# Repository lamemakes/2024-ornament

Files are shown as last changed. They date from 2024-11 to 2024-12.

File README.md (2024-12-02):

# ✨ Blinky Tree ✨

**A super simple holiday ornament that whimsically blinks some LEDs**

## How's it work?

This utilizes [charlieplexing](https://en.wikipedia.org/wiki/Charlieplexing) & an ATTiny85 to control 12 LEDs. When it isn't flashing it's LEDs due to a button trigger, the ATTiny is in a state of [deep sleep ](https://onlinedocs.microchip.com/oxy/GUID-317042D4-BCCE-4065-BB05-AC4312DBC2C4-en-US-2/GUID-0EC704BC-648F-4BF6-90AE-0FAF9C596013.html) and thus using very little power, which is why it can be powered with a CR2032.

## Pics

*Schematic*
2024 Tree Ornament Schematic

*PCB*
2024 Tree Ornament PCB

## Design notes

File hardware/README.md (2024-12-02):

# ⚙️ Blinky Tree Hardware

## BOM

| Part No. | Link | Quantity | Notes | 
|---|---|---|---|
| BC-2003-FH-TR | https://www.digikey.com/en/products/detail/mpd-memory-protection-devices/BC-2003-FH-TR/16692312 | 1 | CR2032 Battery Holder |
| 151031VS06000 | https://www.digikey.com/en/products/detail/w%C3%BCrth-elektronik/151031VS06000/4489988 | 6 | Green LED |
| 151031SS06000 | https://www.digikey.com/en/products/detail/w%C3%BCrth-elektronik/151031SS06000/4489982 | 6 | Red LED |
| TL1107BF130WQ | https://www.digikey.com/en/products/detail/e-switch/TL1107BF130WQ/378978 | 1 | Button |
| ATTINY85-20PU-ND | https://www.digikey.com/en/products/detail/microchip-technology/ATTINY85-20PU/735469 | 1 | "Brains" of the operation |
| CF18JT200R | https://www.digikey.com/en/products/detail/stackpole-electronics-inc/CF18JT200R/1741632 | 4 | 200Ω Resistor |
| CF18JT10K0 | https://www.digikey.com/en/products/detail/stackpole-electronics-inc/cf18jt10k0/1741566 | 1 | 10kΩ Resistor |

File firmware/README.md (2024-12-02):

# 🧑‍💻 Blinky Tree Firmware

## About

Nothing but bare metal (C) & AVR libraries here!

## Building & flashing

The Makefile utilized here was built on a linux machine using an [Arduino as ISP](https://docs.arduino.cc/built-in-examples/arduino-isp/ArduinoISP/) (located on the host machine at `/dev/ttyUSB0`) to flash the code to the ATTiny85. Your set up may vary and this can mostly be configured via the variables at the top of the Makefile.

Once configured, just run `make` to build & flash the firmware!

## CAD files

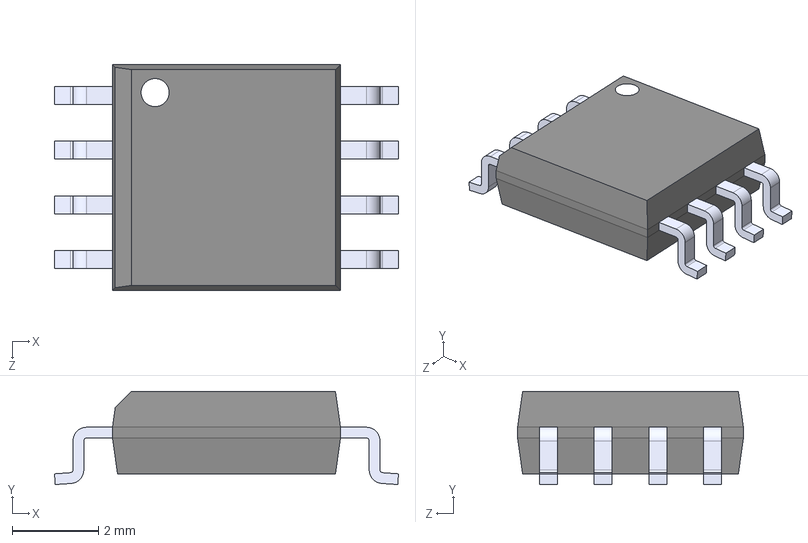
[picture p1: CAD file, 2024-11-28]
hardware/3d_models/ATTINY85-20SUR.step
7.98 x 2.16 x 5.24 mm

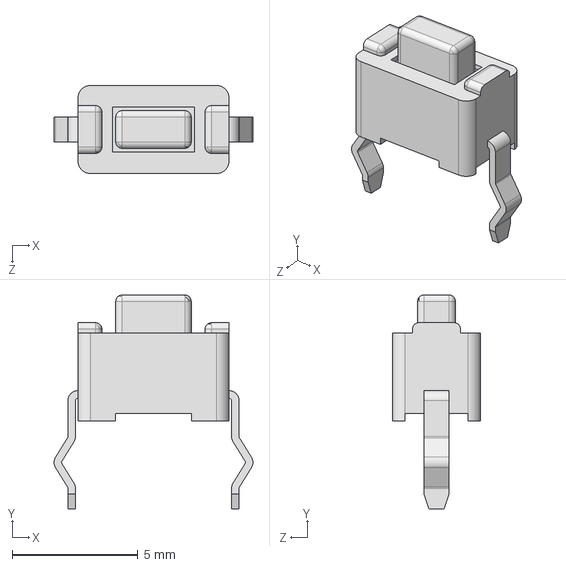
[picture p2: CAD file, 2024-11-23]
hardware/3d_models/TL1107BF130WQ.step
7.90 x 8.50 x 3.50 mm

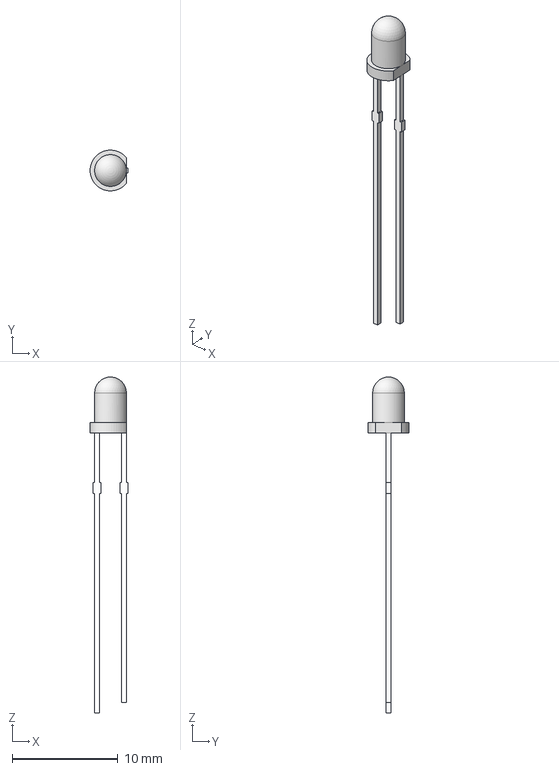
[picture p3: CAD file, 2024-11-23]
hardware/3d_models/WL-TMRC_3MM_LED.step
3.57 x 3.85 x 31.7 mm

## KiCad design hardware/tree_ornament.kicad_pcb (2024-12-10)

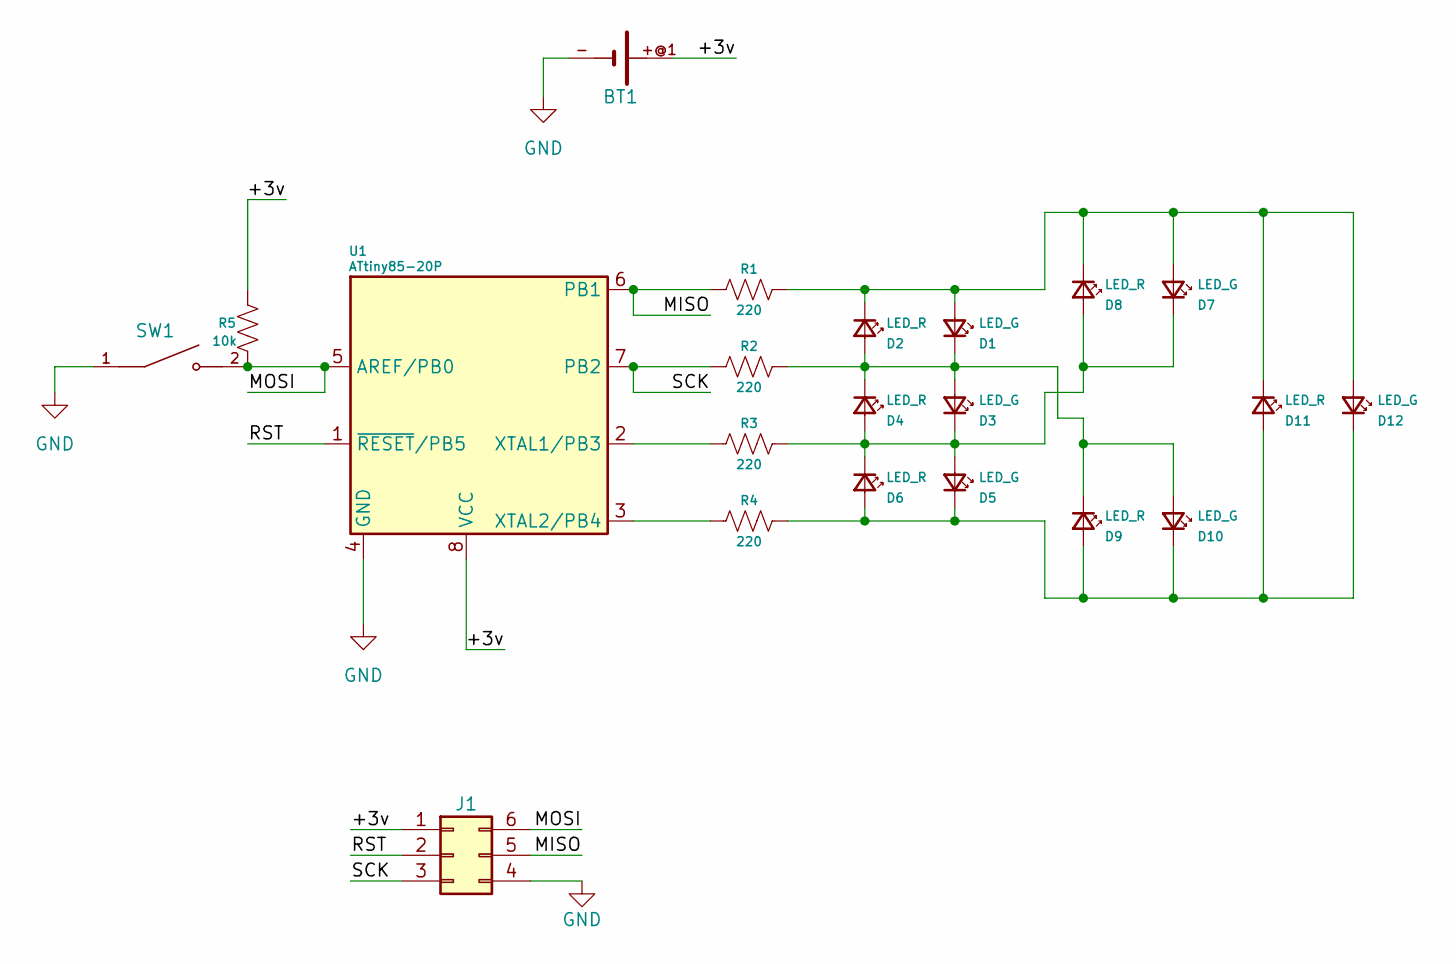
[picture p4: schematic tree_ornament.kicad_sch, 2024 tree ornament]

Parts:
BT1: 3002; BAT_3002
D1, D3, D5, D7, D10, D12: LED_G; WL-TMRC_3MM_LED
D2, D4, D6, D8, D9, D11: LED_R; WL-TMRC_3MM_LED
J1: Conn_02x03_Counter_Clockwise; PinHeader_2x03_P2.54mm_Vertical
R1, R2, R3, R4: 220; R_Axial_DIN0204_L3.6mm_D1.6mm_P7.62mm_Horizontal
R5: 10k; R_Axial_DIN0204_L3.6mm_D1.6mm_P7.62mm_Horizontal
SW1: TL1107BF130WQ; SW_TL1107BF130WQ
U1: ATtiny85-20P; SOIC127P798X216-8N

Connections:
/+3v: BT1.+@1, J1.1, R5.1, U1.8 (VCC)
/MISO: J1.5, R1.2, U1.6 (PB1)
/MOSI: J1.6, R5.2, SW1.2, U1.5 (AREF/PB0)
/RST: J1.2, U1.1 (~RESET/PB5)
/SCK: J1.3, R2.2, U1.7 (PB2)
GND: BT1.-, J1.4, SW1.1, U1.4 (GND)
unnamed: D1.1 (A), D2.2 (K), D7.1 (A), D8.2 (K), D11.2 (K), D12.1 (A), R1.1
unnamed: D1.2 (K), D2.1 (A), D3.1 (A), D4.2 (K), D9.2 (K), D10.1 (A), R2.1
unnamed: D3.2 (K), D4.1 (A), D5.1 (A), D6.2 (K), D7.2 (K), D8.1 (A), R3.1
unnamed: D5.2 (K), D6.1 (A), D9.1 (A), D10.2 (K), D11.1 (A), D12.2 (K), R4.1
unnamed: R3.2, U1.2 (XTAL1/PB3)
unnamed: R4.2, U1.3 (XTAL2/PB4)

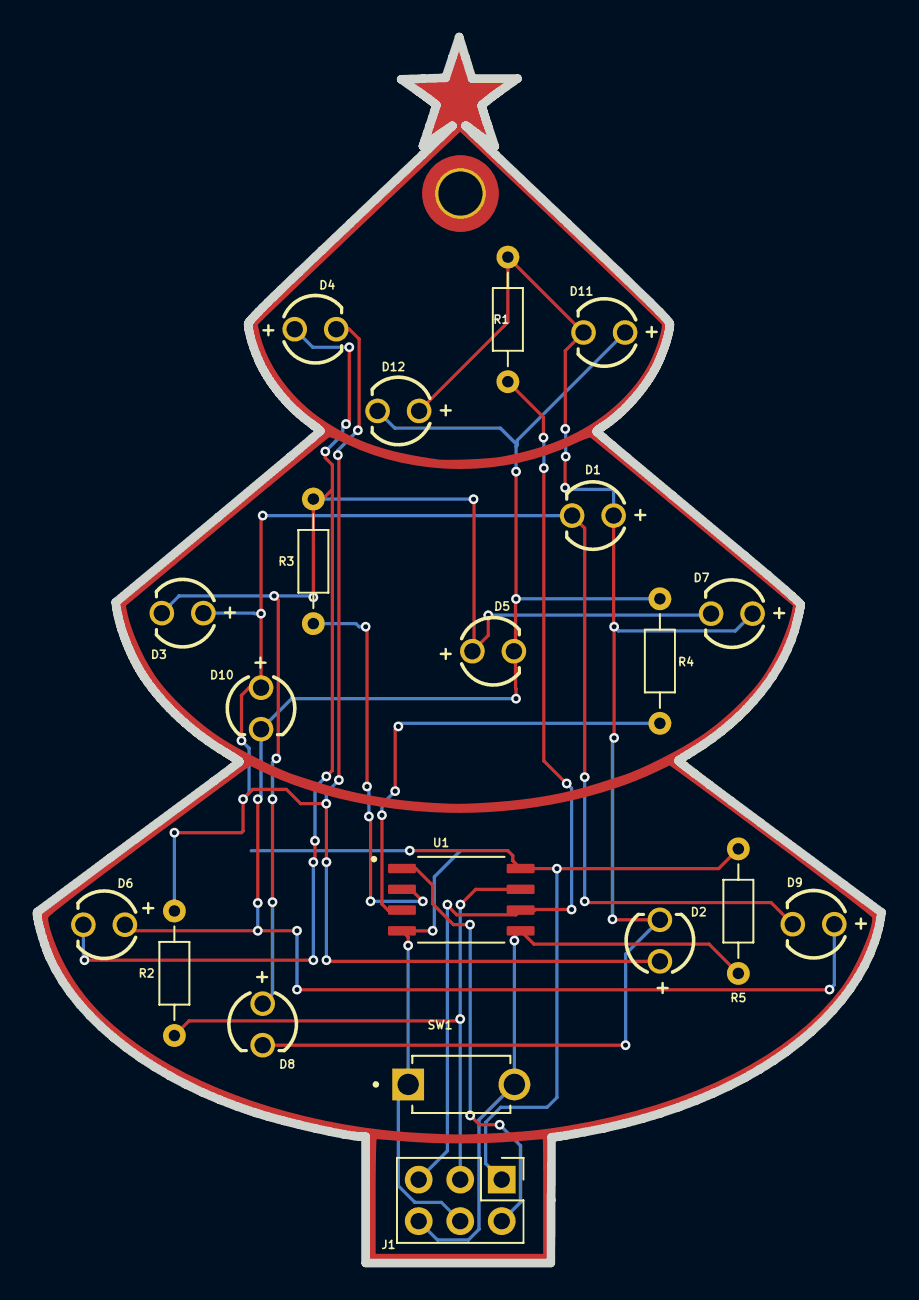
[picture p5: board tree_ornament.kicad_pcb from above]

Board: 2 copper layers, 51.7 x 75.0 mm, 21 parts (1 on the bottom side), 12 nets.

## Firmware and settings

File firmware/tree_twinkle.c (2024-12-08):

#include <avr/io.h>
#include <avr/interrupt.h>
#include <avr/sleep.h>
#include <util/delay.h>
#include "tree_twinkle.h"

void toggle_led(LED led){
    // Set all back to input pins besides the high & low pins
    DDRB = (1 << led.highPin | 1 << led.lowPin);
    PORTB = 1 << led.highPin;
}


void blink_leds(){
    for (int i = 0; i < LED_COUNT; i++) {
        toggle_led(ledArray[i]);
        _delay_ms(500);
    }

    DDRB = 0;
    PORTB = 0;
}

ISR(PCINT0_vect) {
    // ikik don't use delay during an interrupt but... it works? ¯\_(ツ)_/¯ 
    blink_leds();
}

int main(void){

    ADCSRA = 0;             // Disable ADC
    GIMSK = 1 << 5;         // General Interrupt Mask Register - Enable Pin Change Interrupts (for button)
    PCMSK = 1 << BUTTON;    // Pin Change Mask Register - Set PB0 as the PCINT pin (button pin)
    sei();                  // Enable interrupts

    blink_leds();           // She's alive

    while(1){
        // Sleep on a loop - ISR will restart this loop
        // For more info, see
        // https://onlinedocs.microchip.com/oxy/GUID-317042D4-BCCE-4065-BB05-AC4312DBC2C4-en-US-2/GUID-0EC704BC-648F-4BF6-90AE-0FAF9C596013.html
        sleep_enable();
        set_sleep_mode(SLEEP_MODE_PWR_DOWN);  
        sleep_cpu();
    }
}

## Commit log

2024-11-28 Added silkscreen/edge cuts, placed footprints, initial release
    [ATTINY85-20SUR.step, tree_ornament.kicad_pcb, tree_ornament.kicad_sch]
2024-11-29 Update KiCad Image
2024-12-08 Found unconnected LEDs, cleaned up firmware code
    [tree_ornament.kicad_pcb, tree_ornament.kicad_sch]
2024-12-10 Fixed swapped pins
    [tree_ornament.kicad_pcb, tree_ornament.kicad_sch]
